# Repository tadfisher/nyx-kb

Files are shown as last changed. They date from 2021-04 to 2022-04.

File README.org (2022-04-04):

#+STARTUP: inlineimages

#+html: <p align="center"><img src="doc/nyx-logo.svg" /></p>

#+html: <p align="center">Low-profile, split, wireless, ergonomic keyboard. Lots of keys but not too many.</p>

#+html: <p align="center"><a href="https://github.com/tadfisher/nyx-kb/actions/workflows/build.yml?query=branch%3Amain"><img src="https://github.com/tadfisher/nyx-kb/actions/workflows/build.yml/badge.svg?branch=main" /></a></p>

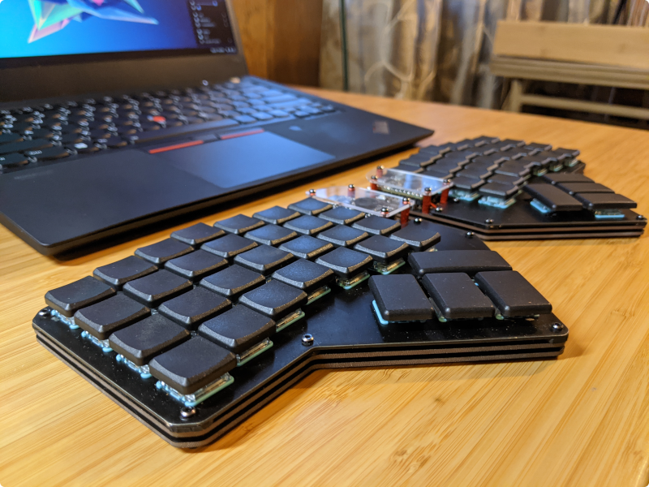
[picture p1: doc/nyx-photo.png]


** Hack

The PCB is a [[https://horizon-eda.org][Horizon EDA]] project in [[file:pcb/][pcb/]]. It requires the [[https://github.com/tadfisher/horizon-kb][horizon-kb pool]], so clone that repo and
add it to your pools in Preferences before opening [[file:pcb/pcb.hprj][pcb/pcb.hprj]].

There is an experimental e-paper adapter board in [[file:epd/][epd/]], but it has not been tested as it ended up
not fitting in the allotted space. This is being worked on.

** Order

For the main PCBs, send off the Gerbers in [[file:pcb/gerbers/nyx.zip][pcb/gerbers/nyx.zip]] to your favorite manufacturing
house. I used [[https://jlcpcb.com/][JLCPCB]] for the prototype build pictured above, but the board should meet design rules
for [[https://oshpark.com/][Oshpark]] and most other houses.

You will need at least two boards for the keyboard halves. The prototype uses an additional
unpopulated board for the bottom plate, which could be less expensive than having one cut from some
other material.

As-is, the board requires either Kailh Choc or MX hotswap sockets.

SVGs for the plates and MCU shield can be found in [[file:case/][case/]]. These are sized in millimeters, so
double-check when you order that you aren't paying for something four times the size you need, as
some cutting services assume the image is sized such that 1px == 1mm. I had [[https://www.sendcutsend.com][SendCutSend]] cut the top
plate out of .048" 304 stainless steel, which fits Kailh Choc (PG1350) switches perfectly. [[https://www.sculpteo.com/en/][Sculpteo]]
cut the MCU shield out of 1mm acrylic which turned out just fine.

I painted the top plates by first scuffing the surface, then applying several thin coats of
[[https://www.amazon.com/gp/product/B003CT498A/][self-etching primer]], followed by several thin coats of [[https://www.amazon.com/gp/product/B07LFWTQJX/][matte-black Krylon Fusion]]. This is a pretty
durable finish, but it may chip slightly at the edges, so a few clear-coats might be desirable.

*** BOM

| QTY | MPN                                            | Description                     | Manufacturer        |
|-----+------------------------------------------------+---------------------------------+---------------------|
|  64 | 1N4148WTR                                      | Diode                           | Diodes Incorporated |
|   2 | MHSS1105                                       | Slide Switch SPDT               | C&K                 |
|  64 | PG1350                                         | Low-profile keyboard switch     | Kailh               |
|  64 | CPG135001S30                                   | Hotswap socket for Kailh PG1350 | Kailh               |
|   2 | PTS636SM25SMTRLFS                              | SMD tactile switch              | C&K                 |
|   2 | nice!nano                                      | BLE microcontroller             | Nice Keyboards      |
|   2 | BM02B-ACHLKS-GAN-ETF                           | Optional battery connector      | JST                 |
|   2 | Generic Pin header 2×3, 2.54mm pitch, vertical | Optional debug header           |                     |
|   2 | Generic Pin header 2×4, 2.54mm pitch, vertical | Optional EPD/OLED header        |                     |

*** Keycaps

Keycaps required:

| QTY | Description |
|-----+-------------|
|  60 | 1u          |
|   6 | 1.5u        |
|   2 | 2u          |

The keycaps shown are MBK Choc (as seen [[https://mkultra.click/mbk-choc-keycaps][here]]), with dimensions:

| Units | Width (mm) | Height (mm) |
|-------+------------+-------------|
| 1u    |       17.5 |        16.5 |
| 1.5u  |       26.5 |        16.5 |
| 2u    |       35.5 |        16.5 |

Switches use 19mm spacing, so MX keycaps (18x18mm) should be compatible.

*** Extras

- 301230 rechargeable battery fits under the nice!nano when using sockets. You can go larger by
  sacrificing some thickness or lopping off the blank area of the top plate under the MCU.
- If using the JST connector, 4x [[https://www.digikey.com/en/products/detail/jst-sales-america-inc/SACHL-003G-P0.2/5272213][ACHL crimp connectors]] and a crimping tool is needed. I used the
  [[https://www.engineertools-jp.com/pa092021][Engineer PA-09]] which worked with some finagling, but the [[https://www.engineertools-jp.com/pad111213][PAD-11]] may be a more appropriate, but
  more expensive, solution. You'll also need two [[https://www.digikey.com/en/products/detail/jst-sales-america-inc/ACHLR-02V-S/5272191][ACHLR connector housings]].
- For standoffs and screws, I bought a few variety packs of [[https://pyrodrone.com/collections/m2/products/diatone-general-screws-pack-m2][M2 screws]] and two sets of
  [[https://pyrodrone.com/collections/m2/products/m2-knurled-aluminum-standoff-5-pcs-choose-lenght][knurled aluminum standoffs]] from [[https://pyrodrone.com/][Pyro Drone]]. I initially used nylon nuts as spacers, but you can
  get thinner by cutting up some rubber hard drive shock mounts. If there's a reliable source of
  rubber/silicone spacers about 1.2mm long, suggestions are welcome!
- For nuts, I eventually shelled out for 4 packs of [[https://www.mcmaster.com/96315A111/][stainless steel M2 hex nuts]] from McMaster-Carr,
  but at US$8.57 per pack of 10, there are certainly cheaper options out there. I used 2mm M2 nylon
  nuts for spacing the bottom plate from the PCB.
- I made a non-slip bottom surface by cutting up a [[https://www.amazon.com/gp/product/B08LN6LN4R/][silicone sheet]] in the shape of the bottom plate
  and using a hole punch to make clearance for the nuts. This particular sheet attracts debris
  though, so suggestions are welcome for alternative materials or feet.

** Solder

#+begin_quote
Tips:

- Use a high-quality flux, and lots of it. You can't use too much flux. I highly suggest [[https://www.amazon.com/ChipQuik-SMD-291-Clean-Syringe-Nozzle/dp/B00CM2A97S][ChipQuik
  tack flux]].
- Clean and tin your iron's tip regularly. I love Hakko's [[https://www.amazon.com/dp/B0195V52J8/][FS-100 tinning paste]] for this.
- Don't go too low on the temperature. I did the whole board at 650°F with leaded solder. You'll
  likely need a higher temperature and more heating time with lead-free solder.
- The board uses surface-mounted components to stay fairly thin. Don't be discouraged; in fact, I
  find it easier to solder small SMT components than to deal with both sides of the board while
  soldering through-hole parts.
#+end_quote

[[file:doc/solder-full.png][file:doc/solder.png]]

Start with the diodes. Moving in columns from left to right (or right-to-left if you're
left-handed), apply flux on the pads labeled =D*= and pre-tin them with a moderate amount of
solder. Re-apply flux. Grab the diode with a pair of tweezers, ensuring it is oriented correctly;
see the image below.

[[file:doc/diode.svg]]

Heat up one pad until the solder is melted and push the diode in from the side until the pin is
seated in the center of the pad. Remove the iron. While pressing down on the diode with the
tweezers, heat up the other pad until the other diode leg is seated and bonded with the solder.

After all the diodes are in place, move on to the switch sockets. Again moving in columns, apply
flux to the pads, tin them with a moderate amount of solder, and re-apply flux. Place the socket,
jam your iron tip in the cup, and apply solder until both the pad and cup are covered and obviously
bonded. These are pretty easy to do, and you can go wild with the solder if you feel like it; just
make sure the bottom of the cup is bonded to the pad.

I recommend soldering the nice!nano sockets now if you're using them; see the
[[https://nicekeyboards.com/docs/nice-nano/getting-started#socketing-the-nicenano][nice!nano documentation]] for a great guide on how to do that. Otherwise, solder the nice!nano itself
to the board, making sure it fits in the silkscreened outline so that you're using the correct set
of pins.

The JST connector can be tricky. What helps here is a minimal amount of tinning on the pad, tons of
flux, and plenty of force with tweezers so it doesn't slide around on you. Start with the smaller
pads first, then anchor with the larger pads.

Solder the reset switch like you did with the diodes.

The through-hole components are the power switch and the optional headers. Be sure to cut off the
excess pin length or you may have interference issues when assembling the board.

If soldering the battery to the nice!nano, use the =B-= and =B+= pins, making sure your polarity is
correct (red = positive, black = negative).

If using the JST connector, crimp the male pins to the battery leads and insert them into the
connector housing, making absolutely sure that the polarity matches the connector socket.

** Building

If using the JST connector, insert the battery first, as the top plate covers the connector.

Place the appropriate-length screws in each of the screw holes in the top plate. On the other side
of the plate, add the spacer of choice; I cut up some rubber HDD shock mounts. Keep in mind you have
1.2mm of space to work with, so normal 2mm nylon nuts won't work.

With the top plate inverted, align the PCB and place it over the screws. Use the nylon nuts to
loosely tie the assembly together.

Turn the board back over. Working from the center out, insert your switches of choice so that they
mount in the socket and clip in to the plate at the same time. I found a thin plastic spudger to be
helpful for spacing apart the plate and PCB, but a pair of tweezers could also work if you're
careful.

After all the switches are inserted, you may want to test the electronics before fully assembling
the board, in case of a bad solder connection or flipped diode. See [[#flashing][Flashing]] below, or use a
multimeter if you like.

Tighten down the spacer nuts underneath the PCB so there isn't play and the switches aren't moving
around when you push them in.

On the bottom plate, insert four screws into the holes surrounding the MCU. Tighten nylon spacer
nuts around these screws so they don't have play.

With the board and bottom plate in either hand, sandwich them together so all the screws protrude
from the holes. Use your nice metal nuts on the bottom.

** Flashing

A configuration for [[https://zmkfirmware.dev/][ZMK Firmware]] lives in [[file:firmware/][firmware/]]. You can grab pre-built images from the [[https://github.com/tadfisher/nyx-kb/actions?query=branch%3Amain][latest
CI run]] by clicking it and downloading the =firmware= artifact. Connect the left board via USB; a
filesystem named =NICENANO= should be mounted. Copy =nyx_left_nice_nano.uf2= into the root folder of
that mount. Likewise, do the same for the right board using =nyx_right_nice_nano.uf2= instead.

Instructions for modifying and building the firmware locally can be found in the
[[https://zmkfirmware.dev/docs][ZMK Firmware documentation]].

** License

Copyright © 2021 Tad Fisher.

All firmware files located in [[file:firmware/][firmware/]] are available under the [[file:LICENSE.mit][MIT]] license to match ZMK.

Except for the third-party works in [[file:doc/][doc/]], all other files are available under the [[file:LICENSE.gpl][GNU GPL version 3
or any later version]].

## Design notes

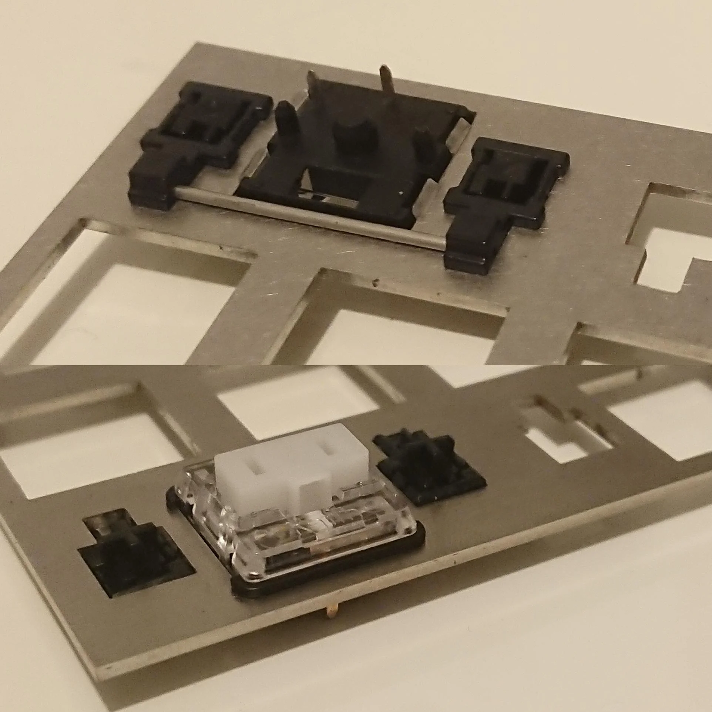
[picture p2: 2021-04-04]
doc/mlxzidavuf041.webp

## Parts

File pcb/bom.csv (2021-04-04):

QTY | MPN | Description | Manufacturer
32 | 1N4148WTR | Small Signal General Purpose Diode | Diodes Incorporated
1 | BM02B-ACHLKS-GAN-ETF | 1.2mm pitch Disconnectable Crimp Style connector | JST
1 | Generic Pin header 2×3, 2.54mm pitch, vertical
1 | Generic Pin header 2×4, 2.54mm pitch, vertical
1 | MHSS1105 | Slide Switch SPDT, Through Hole, Right Angle | APEM Inc.
32 | PG1350 (hotswap) | Low-profile keyboard switch | Kailh
1 | PTS636SM25SMTRLFS | 6.1×3.7×2.5 mm SMD tactile switch, 180 gf actuation force | C&K
1 | nice!nano (reversible) | Pro Micro replacement development board offering BLE using the nRF52840 chip | Nice Keyboards

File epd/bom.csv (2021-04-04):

QTY | MPN | Value | Manufacturer | Ref. Des.
4 | C1608X7R1H104K080AE | 100 nF | TDK | C1, C3, C18, C20
2 | C1608JB1E475K080AC | 4.7 µF | TDK | C2, C19
24 | C1608X7R1E105K080AE | 1 µF | TDK | C4, C5, C6, C7, C8, C9, C10, C11, C12, C13, C15, C17, C21, C22, C23, C24, C25, C26, C27, C28, C29, C30, C32, C34
4 | C1608JB1E225K080AB | 2.2 µF | TDK | C14, C16, C31, C33
2 | MBR0530T1G | MBR0530T1G | ON Semiconductor | D1, D2
2 | SFV30R-2STB1HLF | SFV30R-2STB1HLF | Amphenol FCI | J1, J2
2 | Generic Pin header 2×4, 2.54mm pitch, vertical | Generic Pin header 2×4, 2.54mm pitch, vertical |  | J3, J4

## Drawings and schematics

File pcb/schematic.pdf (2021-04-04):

# E BUSY col1

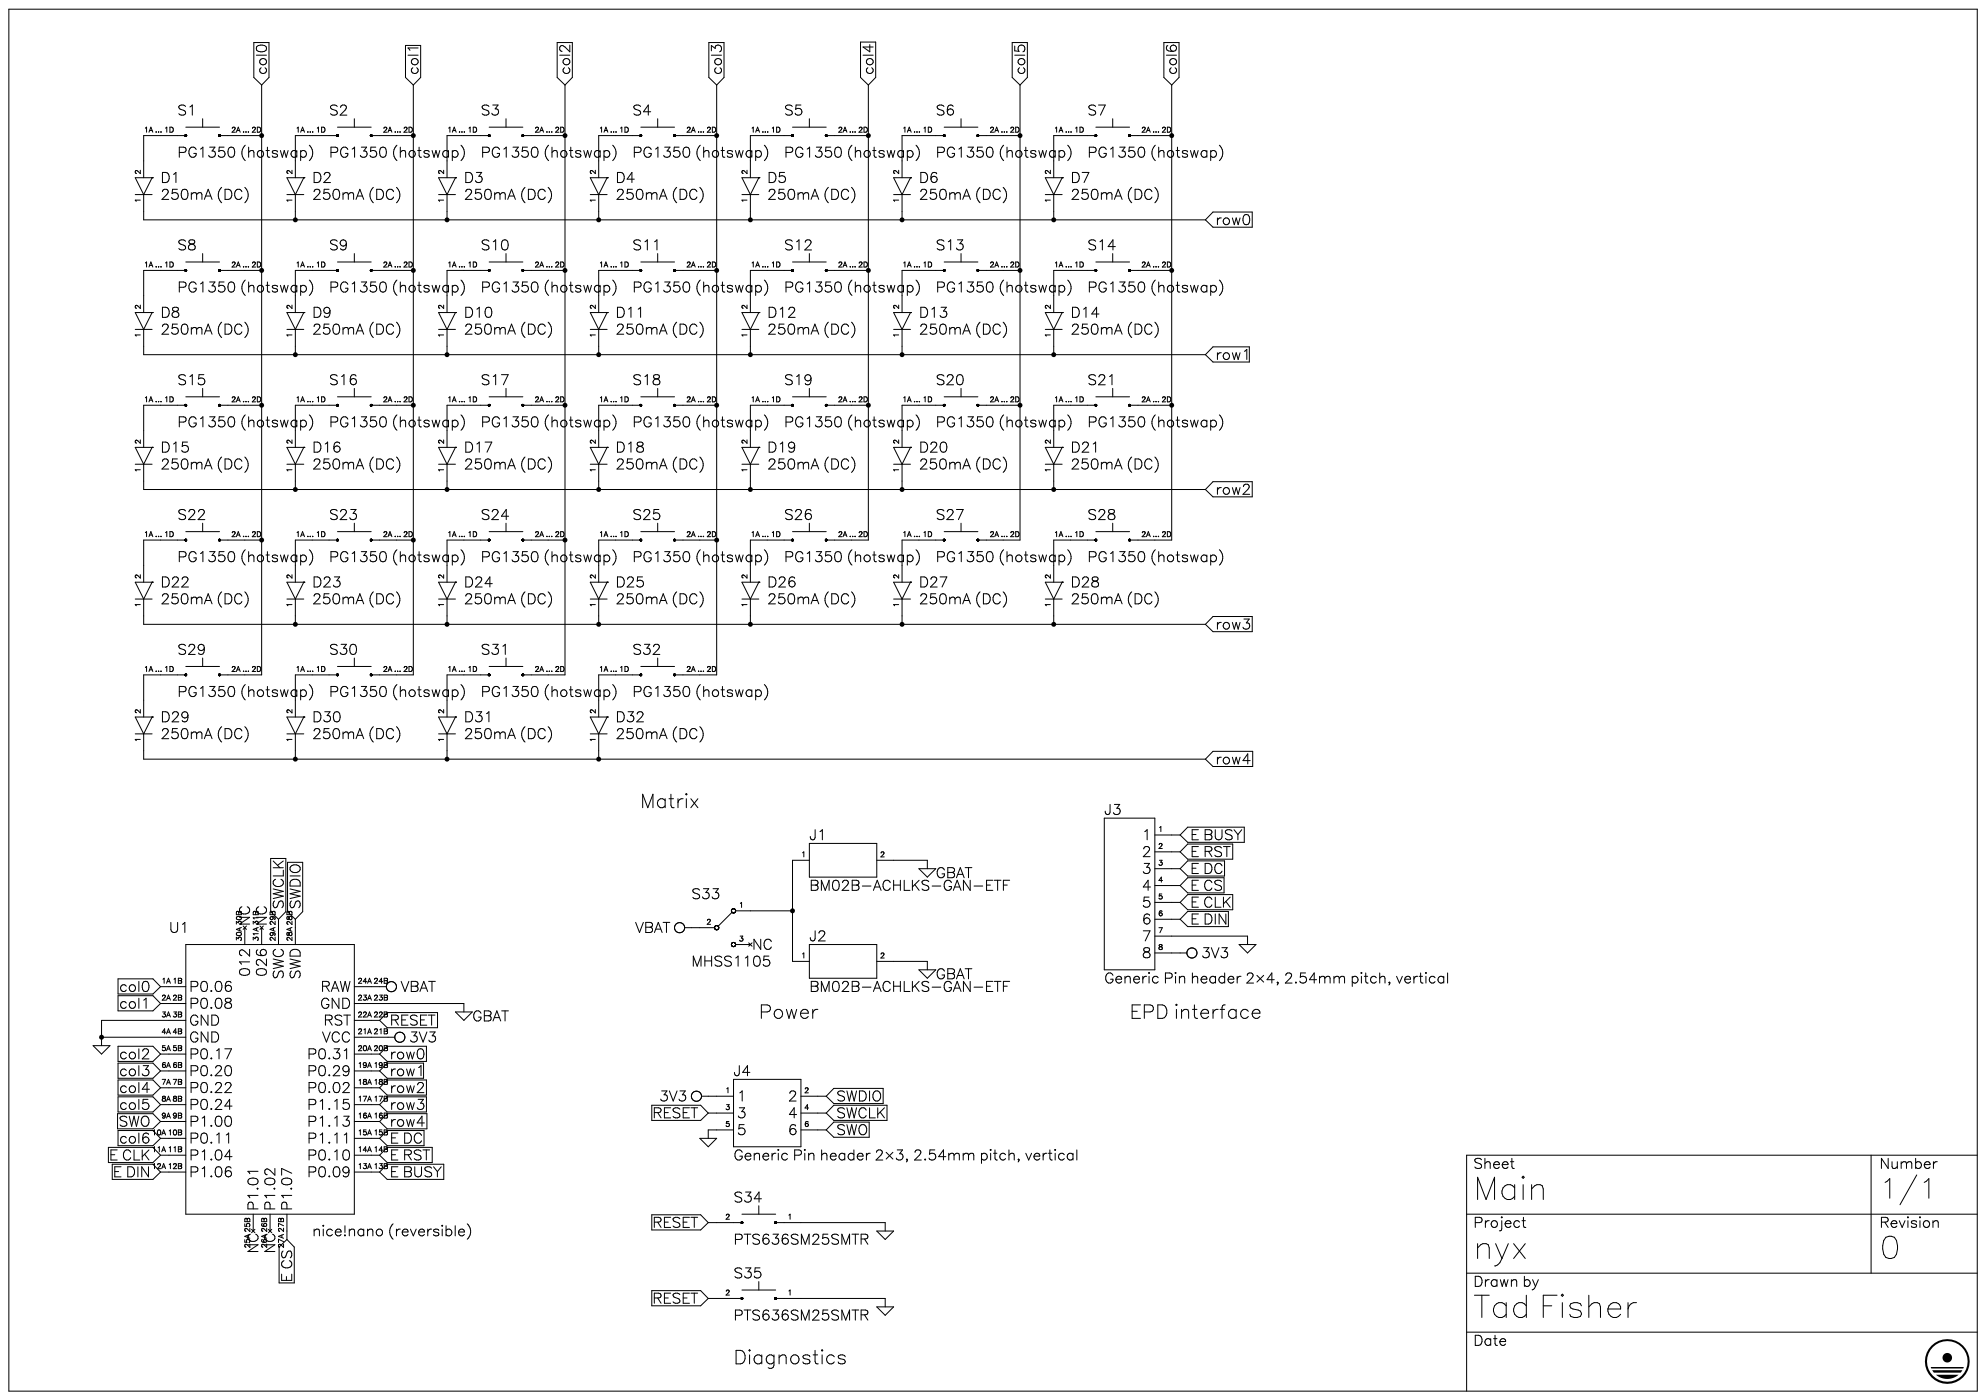
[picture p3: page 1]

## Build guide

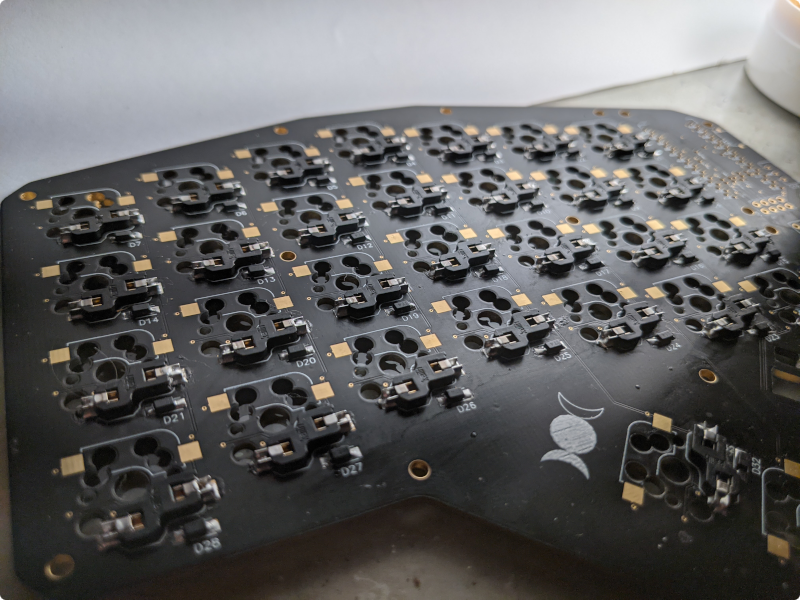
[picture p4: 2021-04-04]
doc/solder.png

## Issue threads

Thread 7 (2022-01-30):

Question about configation of propertied on JLCPCB

aldecode, 2022-01-30:
Hi, a am interested to produce pcb on JLCPCB as you recomended but i confuced with number of configurations, what is correct config here  here?
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

wren, 2022-01-30:
If you use the default options on JLCPCB, and upload the gerber zip file (https://github.com/tadfisher/nyx-kb/blob/main/pcb/gerbers/nyx.zip), it will automatically update the correct options for you. After that, you can optionally change the color and surface finish, and you'll be ready to go.

I just had a batch of these printed up a few weeks ago doing this, and they came out great.

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

tadfisher, 2022-01-31:
Yep, mine were done in black-on-black with the ENIG finish, but there's nothing that requires heavier copper, castellation or whatnot.

I'd love to see your finished work! Glad to know someone else likes this board enough to build one.

aldecode, 2022-01-31:
Thank you guys very much!

Closed 2022-02-01.

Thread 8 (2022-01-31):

What are the caps used in your build?

alieh-rymasheuski, 2022-01-31:
The build instructions are very detailed and list every part used in the build except the key caps. I assumed that some generic Kailh Choc key caps from Aliexpress would fit, but sadly enough, the 2u pieces didn't as they are a bit longer than the PCB allows.

Dimensions:
- 1u: 18x17 mm
- 2u: 34x17 mm

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

UPD: now I can see that the board design lists the lower switches as "1.5u" packages. This would have been a valuable piece of the docs. :)

tadfisher, 2022-01-31:
The keycaps I'm using are MBK (seen here: https://mkultra.click/mbk-choc-keycaps). The dimensions are:

- 1u: 17.5x16.5mm
- 1.5u: 26.5x16.5mm
- 2u: 35.5x16.5mm

I will add the keycap requirements to the BOM, thanks for catching this.

Closed 2022-01-31.

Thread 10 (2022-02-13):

PCB reversible?

husseinalijaafar, 2022-02-13:
Sorry if this is a silly question, just want to confirm, there is only 1 PCB design, and it is reversible?
i.e, the back of the PCB is used for the right-hand side, with diodes etc. soldered on the "back"

tadfisher, 2022-02-13:
Correct!

husseinalijaafar, 2022-02-13:
Perfect thanks!

Closed 2022-02-13.

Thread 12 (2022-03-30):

How to get measurements from the PCB

maxhbr, 2022-03-30:
Hey @tadfisher, this is a great project.

I was thinking about designing (and contributing) a 3d-printable case + switch plate, but I am right now struggling to extract CAD measurements from the Horizon project. (It shows a partial PCB, but is for example lacking the screw holes) My horizon version seems to be newer than the used one, but also some UI parts are just failing to start up.

I was also not able to work with the svg files in the case folder. Maybe you could also generate dxf and step files?

Could you maybe help me to get
* a CAD file (dxf and maybe also step) describing the outline of the PCB, together with
  * coordinates of the screw holes
  * coordinates and orientations of the switches (for the switch plate)

Would be great if there was a way of exporting that from the project.

maxhbr, 2022-04-02:
I got some measurements out of the svg files and started drafting a case, see https://github.com/maxhbr/mynyx/blob/cd15f6f8c3db1698ea6a81bb3e2caf9189fa9efa/case/out/v1.stl

Closed 2022-04-02.

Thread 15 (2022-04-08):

The PCB does not fit 5 Pin Cherry MX switches

maxhbr, 2022-04-08:
The two added supporting pins, that 5 Pin Cherry MX switches have, do not fit the holes in the PCB. The holes in the PCB are to far apart. (tested with Gateron and Gazzew switches)

maxhbr, 2022-04-09:
But it fits 5pin choc switches

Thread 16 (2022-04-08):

Bottom side of PCB has no markings for Diode ortientation

maxhbr, 2022-04-08:
See:
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
on commit https://github.com/tadfisher/nyx-kb/commit/7f54d5e8f3858ddaa04610b931b70e512fd6f7ac

alieh-rymasheuski, 2022-04-13:
@maxhbr, you can solder the diodes on the other side, and it will not make any functional difference. Compare my left and right halves:
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

maxhbr, 2022-04-13:
Ah OK, might be worth clarifying that in the guide.

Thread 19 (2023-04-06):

Question about Item List for Wired Only

yourbro17, 2023-04-06:
Hi, I intend to build this keyboard, but don't need any wireless function, so I wanted to ask if that means that I could just not use the slide switches because the keyboard is only on when connected with usb?
And also, just for clarity, are the PTS636SM25SMTRLFS switches intended as reset switches? If so, I would also plan on not using them, so that I can make a cleaner case and save 20 bucks on shipping costs.

yourbro17, 2023-04-12:
Alright thanks. I guess I will still use the sockets if I ever feel the need to switch to battery powered.

Closed 2023-04-12.

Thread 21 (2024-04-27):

Expected sizes for mcu/plate/case & DXF for plate? (Pretty please)

alist, 2024-04-27:
Hi thank you so much for this project!!

Struggling a bit with the SVGs under `case/` as when I upload them to a Sculpteo, they seem to be detected at the 4x the true size, as you warned about.

Would you be willing to add the "expected" sizes for the mcu/plate/case as a cross-check?

> SVGs for the plates and MCU shield can be found in [case/](https://github.com/tadfisher/nyx-kb/blob/main/case). These are sized in millimeters, so double-check when you order that you aren’t paying for something four times the size you need, as some cutting services assume the image is sized such that 1px == 1mm. I had [SendCutSend](https://www.sendcutsend.com/) cut the top plate out of .048” 304 stainless steel, which fits Kailh Choc (PG1350) switches perfectly. [Sculpteo](https://www.sculpteo.com/en/) cut the MCU shield out of 1mm acrylic which turned out just fine.

I'm also wondering if you'd be willing upload a plate DXF as sendcutsend doesn't support svg and some svg-dxf converters are making mistakes. 😬

First home keeb, and am really looking forward to using this board while on the road.
Thank you so much again!

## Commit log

2021-04-04 Rename PCB project
2021-04-04 Add readme and license info
    [bom.csv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]
2021-04-04 Rotate JST connector
    [nyx.gbl, nyx.gbo, nyx.gbs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]
2021-04-12 650 C → 650°F
2023-07-10 Increase BT transmit power
    See https://zmk.dev/docs/features/bluetooth#connectivity-issues
